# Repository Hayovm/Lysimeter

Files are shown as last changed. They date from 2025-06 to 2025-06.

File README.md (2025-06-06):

📁 Repository Structure
This repository is organized into three main folders to keep everything structured and easy to navigate:

🔌 Code/
Contains the Arduino .ino file and any supporting libraries required to run the lysimeter system.
Open this file in the Arduino IDE to upload it to your microcontroller.

🖨️ STLs_and_Circuit/
Includes:

3D STL files for printing the mechanical parts of the lysimeter.

Wiring and circuit diagrams detailing how to connect the load cells, HX711 modules, SD card module, and RTC to the Arduino.

📖 Manual/
Provides a full user guide:

Step-by-step installation instructions.

Instructions for calibrating and taring the load cells.

List of serial commands you can use via the Arduino IDE.

Proper startup sequence and system handling.

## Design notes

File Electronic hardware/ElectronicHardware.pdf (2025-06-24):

Micro controller, HX711 amplifier, SD card

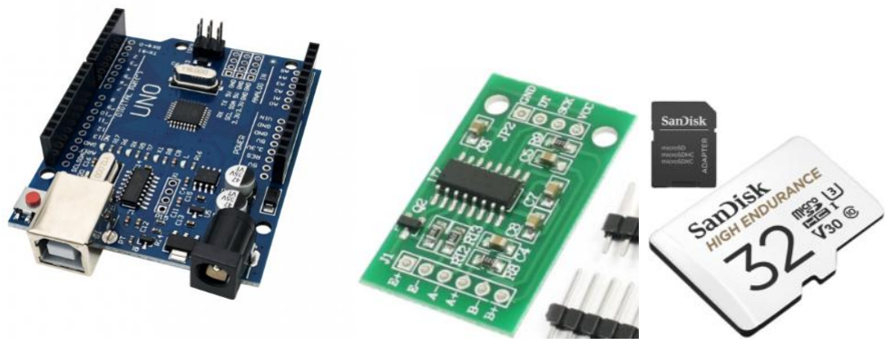
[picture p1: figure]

Prize: 8.50 €
Pin headers: Standard + Extra
USB <-> UART converter: CH340G
Maximum Input voltage on DC jack connection 15V (at 50mA)
12V (at 100mA)
10V (at 300mA)
7V (at 600mA)
Link: tinytronics.nl/en/development-boards/microcontroller-boards/arduino-compatible/uno-r3-compatible-usb-b
SD card:
Prize: 11€
The SD card needs to withstand harsh conditions such as extreme temperatures, water, shock, and X-rays, and must be capable of frequent writing and rewriting for continuous video recording.
Link (too long) google: high endurance SD card.

HX711 amplifier
Prize: 2€
The signal from the loadcells is very small and therefore needs to be amplified, this done through the HX711 load cell amplifier.
Link: https://www.tinytronics.nl/nl/sensoren/gewicht-druk-kracht/load-cellen/load-cell-versterkerhx711

Data logging shield (RTC and SD), load cell
Ensure that the shield used is of reliable quality. During the course of this thesis, the battery contact on the shield failed, resulting in incorrect timestamps. The issue occurred within a few days of use. As the shield was a clone version, it is possible that poor build quality contributed to the malfunction.

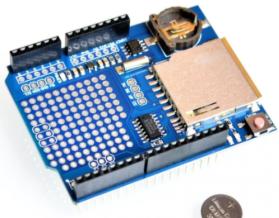
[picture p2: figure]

Prize: 6€
Power Supply: 5V DC
Signal Voltage: 5V

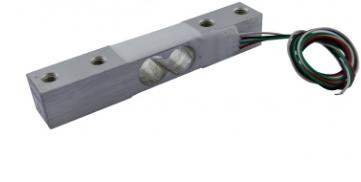
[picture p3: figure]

RTC (Real-Time Clock):
- Chip: DS1307 (make sure to reference this specific chip number in the code!)
- Communication: I2C
- Battery: CR1220 (make sure to check the battery)
Pinout:
- DS1307: A4 (SDA), A5 (SCL)
- SD Card: 10 (CS), 11 (MOSI/DI), 12 (MISO/DO), 13 (CLK) Package Contents:
- 1x Data Logging Shield
- 1x CR1220 Battery
Link: https://www.tinytronics.nl/nl/data-opslag/modules/data-logging-shield

Mavin Load Cell - 2kg
Prize: 6€
Specifications
- Weight Range: 0–2 kg
- Recommended Input Voltage: 5–12V
- Dimensions: See images
Wire Pinout:
- Red: Power (E+)
- White: Signal (A-)
- Black: Power (Ground) (E-)
- Green: Signal (A+)

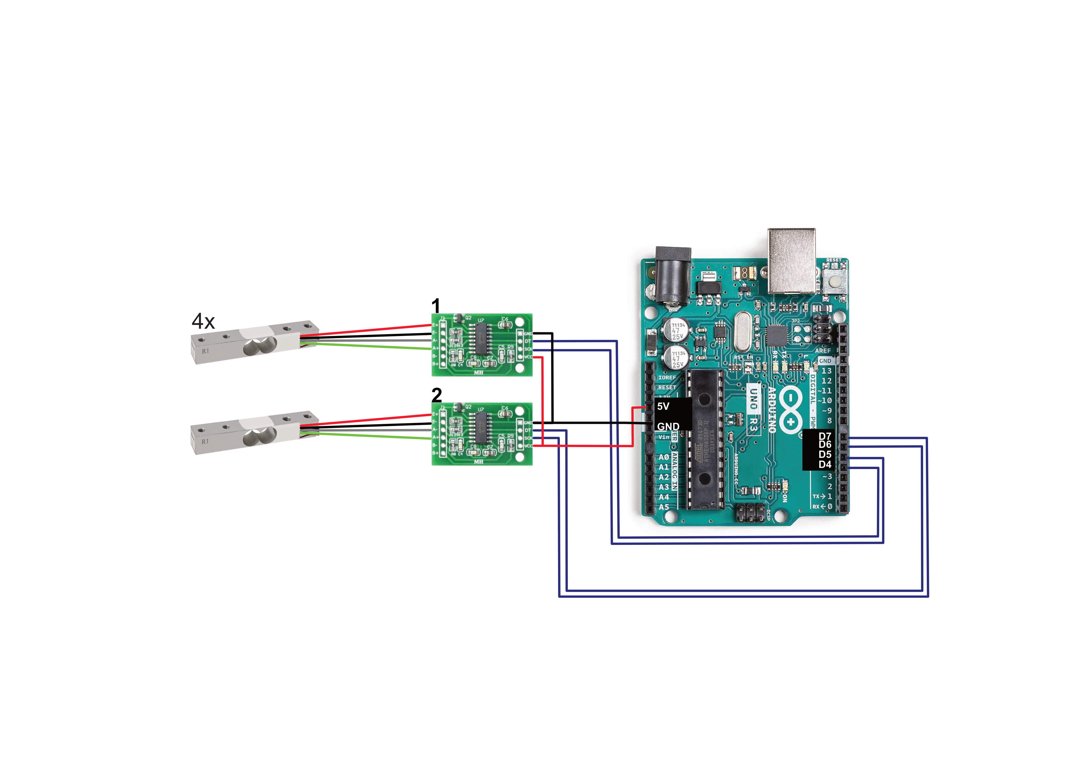
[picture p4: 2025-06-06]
STLs_and_Circuit/HayoElectricCircuit.png

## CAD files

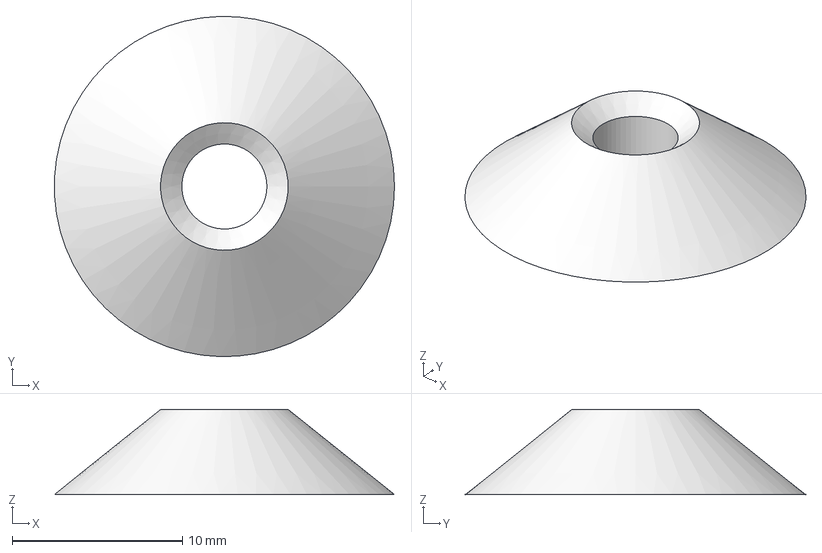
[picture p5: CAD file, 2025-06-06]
STLs_and_Circuit/feet.step
20.0 x 20.0 x 5.00 mm

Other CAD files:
STLs_and_Circuit/Assembly hayo open.STL
STLs_and_Circuit/Feet.FCStd

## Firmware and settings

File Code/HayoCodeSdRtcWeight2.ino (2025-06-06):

#include <HX711_ADC.h>
#include <Wire.h>
#include <RTClib.h>
#include <SD.h>
#include <SPI.h>
#if defined(ESP8266) || defined(ESP32) || defined(AVR)
#include <EEPROM.h>
#endif

// --- Pins ---
const int HX711_dout1 = 4;
const int HX711_sck1  = 5;
const int HX711_dout2 = 6;
const int HX711_sck2  = 7;
const int chipSelect  = 10;
const int led         = 8;

// --- HX711 Instances ---
HX711_ADC LoadCell1(HX711_dout1, HX711_sck1);
HX711_ADC LoadCell2(HX711_dout2, HX711_sck2);

RTC_DS1307 rtc;

// --- EEPROM Calibration Addresses ---
const int calVal1_eepromAddress = 0;
const int calVal2_eepromAddress = 10;

// --- Other Variables ---
char filename[15];  // 8.3 format
int selectedCell = 1;
unsigned long lastLogTime = 0;
const unsigned long logInterval = 60000; // adjust for logging interval between measurements (milliseconds)

// --- Function Prototypes ---
void processSerialCommands();
void calibrateSelectedLoadCell();
void handleCalibrationInput();

void setup() {
  pinMode(led, OUTPUT);
  digitalWrite(led, LOW);

  Serial.begin(57600);
  delay(100);
  Serial.println(F("Starting..."));

  // --- RTC Init ---
  if (!rtc.begin()) {
    Serial.println(F("Couldn't find RTC"));
    while (1);
  }

  DateTime now = rtc.now();
  Serial.print(F("RTC reported time: "));
  Serial.println(now.timestamp(DateTime::TIMESTAMP_FULL));

  if (!rtc.isrunning()) {
    Serial.println(F("RTC is NOT running, setting to compile time."));
    rtc.adjust(DateTime(F(__DATE__), F(__TIME__)));
  } else {
    Serial.println(F("RTC is running."));
  }

  if (now.year() < 2020) {
    Serial.println(F("Warning: RTC time seems invalid. Battery may be missing or dead."));
  }

  // --- Create Filename (8.3 format) ---
  snprintf(filename, sizeof(filename), "L%02d%02d%02d.TXT", now.year() % 100, now.month(), now.day());
  Serial.print(F("Logging to file: "));
  Serial.println(filename);

  // --- SD Init ---
  Serial.print(F("Initializing SD card..."));
  if (!SD.begin(chipSelect)) {
    Serial.println(F("SD card initialization failed!"));
    while (1);
  }
  Serial.println(F("SD card ready."));

  if (!SD.exists(filename)) {
    File dataFile = SD.open(filename, FILE_WRITE);
    if (dataFile) {
      dataFile.println(F("Timestamp, weight 1, weight 2"));
      dataFile.close();
      Serial.println(F("Created new log file with header."));
    } else {
      Serial.println(F("Failed to create file."));
    }
  }

  // --- Load Cell 1 Init ---
  float cal1;
EEPROM.get(calVal1_eepromAddress, cal1);
if (isnan(cal1) || cal1 == 0) {
  Serial.println("Invalid cal factor in EEPROM. Using default.");
  cal1 = 696.0;  // replace with your known good value
}
Serial.print("Using LoadCell1 cal factor: ");
Serial.println(cal1);
LoadCell1.begin();
LoadCell1.setCalFactor(cal1);
  LoadCell1.setSamplesInUse(3);
  LoadCell1.start(2000, true);
  if (LoadCell1.getTareTimeoutFlag()) {
    Serial.println(F("Tare timeout on LoadCell1"));
    while (1);
  }
  LoadCell1.setCalFactor(cal1);

  // --- Load Cell 2 Init ---
  float cal2 = 345.0;
  EEPROM.get(calVal2_eepromAddress, cal2);
  LoadCell2.begin();
  LoadCell2.setSamplesInUse(3);
  LoadCell2.start(2000, true);
  if (LoadCell2.getTareTimeoutFlag()) {
    Serial.println(F("Tare timeout on LoadCell2"));
    while (1);
  }
  LoadCell2.setCalFactor(cal2);

  Serial.println(F("System ready. Send '1' or '2' to calibrate LoadCell1 or LoadCell2."));
  Serial.println(F("To set RTC time, use: set YYYY MM DD HH MM SS"));
  Serial.println(F("To view current time, send: time"));
}

void loop() {
  // --- Continuously update sensors for responsive data ---
  LoadCell1.update();
  LoadCell2.update();

  // --- Log once per minute ---
  if (millis() - lastLogTime >= logInterval) {
    float weight1 = LoadCell1.getData();
    float weight2 = LoadCell2.getData();
    DateTime now = rtc.now();

    // --- LED ON during SD write (1-second blink) ---
    digitalWrite(led, HIGH);

    // --- Serial print ---
    Serial.print(now.timestamp(DateTime::TIMESTAMP_FULL));
    Serial.print(F(" - W1: "));
    Serial.print(weight1, 2);
    Serial.print(F(" g, W2: "));
    Serial.println(weight2, 2);

    // --- Write to SD ---
    File dataFile = SD.open(filename, FILE_WRITE);
    if (dataFile) {
      dataFile.print(now.year(), DEC); dataFile.print("-");
      dataFile.print(now.month(), DEC); dataFile.print("-");
      dataFile.print(now.day(), DEC); dataFile.print(" ");
      dataFile.print(now.hour(), DEC); dataFile.print(":");
      dataFile.print(now.minute(), DEC); dataFile.print(":");
      dataFile.print(now.second(), DEC); dataFile.print(",");
      dataFile.print(weight1, 2); dataFile.print(",");
      dataFile.println(weight2, 2);
      dataFile.close();
    } else {
      Serial.println(F("SD write error."));
    }

    delay(1000);  // keep LED on for visibility
    digitalWrite(led, LOW);  // signal safe to remove card

    lastLogTime = millis();
  }

  // Optional: check for commands
  processSerialCommands();
  handleCalibrationInput();

  // Show tare status
  if (LoadCell1.getTareStatus()) Serial.println(F("Tare complete on LoadCell1"));
  if (LoadCell2.getTareStatus()) Serial.println(F("Tare complete on LoadCell2"));
}

void handleCalibrationInput() {
  if (Serial.available()) {
    char cmd = Serial.peek();
    if (cmd == '1' || cmd == '2' || cmd == 't') {
      char c = Serial.read();
      if (c == '1' || c == '2') {
        selectedCell = c - '0';
        Serial.print(F("Selected LoadCell"));
        Serial.println(selectedCell);
        calibrateSelectedLoadCell();
      } else if (c == 't') {
        if (selectedCell == 1) LoadCell1.tareNoDelay();
        else if (selectedCell == 2) LoadCell2.tareNoDelay();
      }
    }
  }
}

void calibrateSelectedLoadCell() {
  HX711_ADC* cell;
  int eepromAddr;

  if (selectedCell == 1) {
    cell = &LoadCell1;
    eepromAddr = calVal1_eepromAddress;
  } else {
    cell = &LoadCell2;
    eepromAddr = calVal2_eepromAddress;
  }

  Serial.println(F("*** Calibration ***"));
  Serial.println(F("Remove weight and send 't' to tare."));
  while (true) {
    cell->update();
    if (Serial.available()) {
      char inByte = Serial.read();
      if (inByte == 't') {
        cell->tareNoDelay();
        Serial.println(F("Taring..."));
      }
    }
    if (cell->getTareStatus()) {
      Serial.println(F("Tare complete."));
      break;
    }
  }

  Serial.println(F("Place known mass and send its value (e.g., 100.0):"));
  float knownMass = 0.0;
  while (knownMass == 0.0) {
    if (Serial.available()) {
      knownMass = Serial.parseFloat();
    }
  }
  Serial.print(F("Known mass entered: "));
  Serial.println(knownMass);

  cell->refreshDataSet();
  float newCal = cell->getNewCalibration(knownMass);
  Serial.print(F("New calibration factor: "));
  Serial.println(newCal, 5);

  Serial.print(F("Save to EEPROM at address "));
  Serial.print(eepromAddr);
  Serial.println(F("? (y/n)"));

  while (true) {
    if (Serial.available()) {
      char confirm = Serial.read();
      if (confirm == 'y') {
#if defined(ESP8266) || defined(ESP32)
        EEPROM.begin(512);
#endif
        EEPROM.put(eepromAddr, newCal);
#if defined(ESP8266) || defined(ESP32)
        EEPROM.commit();
#endif
        Serial.println(F("Calibration saved."));
        break;
      } else if (confirm == 'n') {
        Serial.println(F("Calibration not saved."));
        break;
      }
    }
  }
}

void processSerialCommands() {
  if (Serial.available()) {
    String input = Serial.readStringUntil('\n');
    input.trim();

    if (input.startsWith("set")) {
      int yr, mo, dy, hr, min, sec;
      int count = sscanf(input.c_str(), "set %d %d %d %d %d %d", &yr, &mo, &dy, &hr, &min, &sec);
      if (count == 6) {
        rtc.adjust(DateTime(yr, mo, dy, hr, min, sec));
        Serial.println(F("RTC time set successfully."));
      } else {
        Serial.println(F("Invalid format. Use: set YYYY MM DD HH MM SS"));
      }
    } else if (input == "time") {
      DateTime now = rtc.now();
      Serial.print(F("Current RTC time: "));
      Serial.println(now.timestamp(DateTime::TIMESTAMP_FULL));
    }
  }
}

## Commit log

2025-06-06 Code
    Code for Arduino IDE to power 4 load cells in a single output and 1 load cell as a reference output. Data is connected with a timestamp and saved on a SD
2025-06-06 Rename Assembly hayo dicht.STL to STLs_and_Circuit/ Assembly hayo dicht.STL
    [Assembly hayo dicht.STL]
2025-06-06 Rename Assembly hayo open.STL to STLs_and_Circuit/Assembly hayo open.STL
    [Assembly hayo open.STL]
2025-06-06 Update and rename feet.step to STLs_and_Circuit/feet.step
    [feet.step]
